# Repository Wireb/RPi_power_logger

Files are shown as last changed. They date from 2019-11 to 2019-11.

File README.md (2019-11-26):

# RPi Power Logger
These files are for my Raspberry Pi Zero based power data logger hat. 
 
License is MIT so do what you want with it just don't litigate me. 

Have had quite a few times where I needed actual run times of various battery powered devices. Built this device to collect both the battery voltage, current, and average power as well as up to 8 other voltage rails.

The simple use case is to put channel 0 in line with your battery powered device. This channel is based on the TI INA233 Bidirectional current and power sensor. It supports up to 36Vin and a wide range of currents depending on your choice for R17 and scaling factor. See the INA233 datasheet for more info. In my case of small battery powered devices I have optimized for a max current of 2A. Note the INA233 is set up for high side sensing and the RPi must be powered externally with a common ground with the circuit under test. Once inserted in the power lines just log into the Pi and start the perl script. It will generate a ./Power_data.csv file with all the readings taken every second until you kill the process. 

More advanced setups can use channels 1 - 8 to monitor internal voltage rails. I use this to see which rail is failing first and if any become unstable when the battery voltage is low. Channels 1 - 3 support up to 4V max, channles 4 - 6 support up to 6V max, and channels 7 and 8 support up to 15V max. Note all channels are on a common ground reference.

There is configuration variables in the Perl script for which channels to sample, time between samples, max sample time, and some INA233 configuration. (see Raspbian-Perl directory for more info)

## KiCad
This is a KiCad 5.1.4 project. Both the original KiCad logics, PCB files and a xlsx bill of material can be found here as well as a PDF file of the logics and a top side image of the PCB.   

## Raspbian-Perl
This is the perl script I use to collect the data on the Raspberry Pi. Sample output .csv file of just channel 0 and a processed graph in xlsx format are also included. 

Copyright (c) 2019 Peter Shabino

Permission is hereby granted, free of charge, to any person obtaining a copy of this hardware, software, and associated documentation files 
(the "Product"), to deal in the Product without restriction, including without limitation the rights to use, copy, modify, merge, publish, 
distribute, sublicense, and/or sell copies of the Product, and to permit persons to whom the Product is furnished to do so, subject to the 
following conditions:

The above copyright notice and this permission notice shall be included in all copies or substantial portions of the Product.

THE PRODUCT IS PROVIDED "AS IS", WITHOUT WARRANTY OF ANY KIND, EXPRESS OR IMPLIED, INCLUDING BUT NOT LIMITED TO THE WARRANTIES OF 
MERCHANTABILITY, FITNESS FOR A PARTICULAR PURPOSE AND NONINFRINGEMENT. IN NO EVENT SHALL THE AUTHORS OR COPYRIGHT HOLDERS BE LIABLE 
FOR ANY CLAIM, DAMAGES OR OTHER LIABILITY, WHETHER IN AN ACTION OF CONTRACT, TORT OR OTHERWISE, ARISING FROM, OUT OF OR IN CONNECTION 
WITH THE PRODUCT OR THE USE OR OTHER DEALINGS IN THE PRODUCT.

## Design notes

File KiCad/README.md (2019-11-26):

# KiCad project files
These are KiCad 5.1.4 compatible files. Not going any deeper than that :)

If you just want PCBs now they are available on OSHpark here: 
https://oshpark.com/shared_projects/NPSVbO1J


## partnumber.csv
CSV file of all unique part numbers. (used for ordering)

## refdes.csv
CSV file of every part by refdes. (used for building)

## RPi_power_logger.xlsx
Bill of Materials in Microsoft Excel format. Includes links to Digikey. 

## RPi_power_logger.pdf
PDF file of logics for easy viewing without KiCad installed. 

## RPi_power_logger_PCB.png
Image file of the top side of the PCB and refdes for easy viewing without KiCad installed. 

Copyright (c) 2019 Peter Shabino

Permission is hereby granted, free of charge, to any person obtaining a copy of this hardware, software, and associated documentation files 
(the "Product"), to deal in the Product without restriction, including without limitation the rights to use, copy, modify, merge, publish, 
distribute, sublicense, and/or sell copies of the Product, and to permit persons to whom the Product is furnished to do so, subject to the 
following conditions:

The above copyright notice and this permission notice shall be included in all copies or substantial portions of the Product.

THE PRODUCT IS PROVIDED "AS IS", WITHOUT WARRANTY OF ANY KIND, EXPRESS OR IMPLIED, INCLUDING BUT NOT LIMITED TO THE WARRANTIES OF 
MERCHANTABILITY, FITNESS FOR A PARTICULAR PURPOSE AND NONINFRINGEMENT. IN NO EVENT SHALL THE AUTHORS OR COPYRIGHT HOLDERS BE LIABLE 
FOR ANY CLAIM, DAMAGES OR OTHER LIABILITY, WHETHER IN AN ACTION OF CONTRACT, TORT OR OTHERWISE, ARISING FROM, OUT OF OR IN CONNECTION 
WITH THE PRODUCT OR THE USE OR OTHER DEALINGS IN THE PRODUCT.

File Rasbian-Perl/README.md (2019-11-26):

# RPi_datalogger.pl
This is the main Perl script for data logging. 
Edit the file in any text editor to configure the following:

```perl
############################
# configuration value start
############################
my $output_file = "./Power_data.csv";	# output file path and name for readings
my $stop_file = "./stop";				# file to create to stop the loop
my $channels = "12345678"; 				# optional voltage channels enables. Valid values are 1 to 8. If that number is in this string (any order) the data will be collected along with the power data. 
my $sample_every = 1;					# sample every x seconds. A value of 0 will sample as fast as possible but the time data will still be in seconds (future upgrade sub second time base) 
my $stop_time = 0;						# in s 0 = run forever
############################
# configuration value end
############################

# constants (See INA233 datasheet for more info!!)
my $max_current = 2;	# in Amps
my $R_shunt = 0.075;  	# in Ohms
```

## Power_data.csv
This is a sample raw CSV file as produced by the above Perl script.

Note only channle 0 was enabled in this sample. If channels 1 - 8 were enabled there would be one more voltage column per enabled channel. 

## Sample_graph.xlsx
Example Microsoft Excel spreadsheet with a graph of the sample data. 

Copyright (c) 2019 Peter Shabino

Permission is hereby granted, free of charge, to any person obtaining a copy of this hardware, software, and associated documentation files 
(the "Product"), to deal in the Product without restriction, including without limitation the rights to use, copy, modify, merge, publish, 
distribute, sublicense, and/or sell copies of the Product, and to permit persons to whom the Product is furnished to do so, subject to the 
following conditions:

The above copyright notice and this permission notice shall be included in all copies or substantial portions of the Product.

THE PRODUCT IS PROVIDED "AS IS", WITHOUT WARRANTY OF ANY KIND, EXPRESS OR IMPLIED, INCLUDING BUT NOT LIMITED TO THE WARRANTIES OF 
MERCHANTABILITY, FITNESS FOR A PARTICULAR PURPOSE AND NONINFRINGEMENT. IN NO EVENT SHALL THE AUTHORS OR COPYRIGHT HOLDERS BE LIABLE 
FOR ANY CLAIM, DAMAGES OR OTHER LIABILITY, WHETHER IN AN ACTION OF CONTRACT, TORT OR OTHERWISE, ARISING FROM, OUT OF OR IN CONNECTION 
WITH THE PRODUCT OR THE USE OR OTHER DEALINGS IN THE PRODUCT.

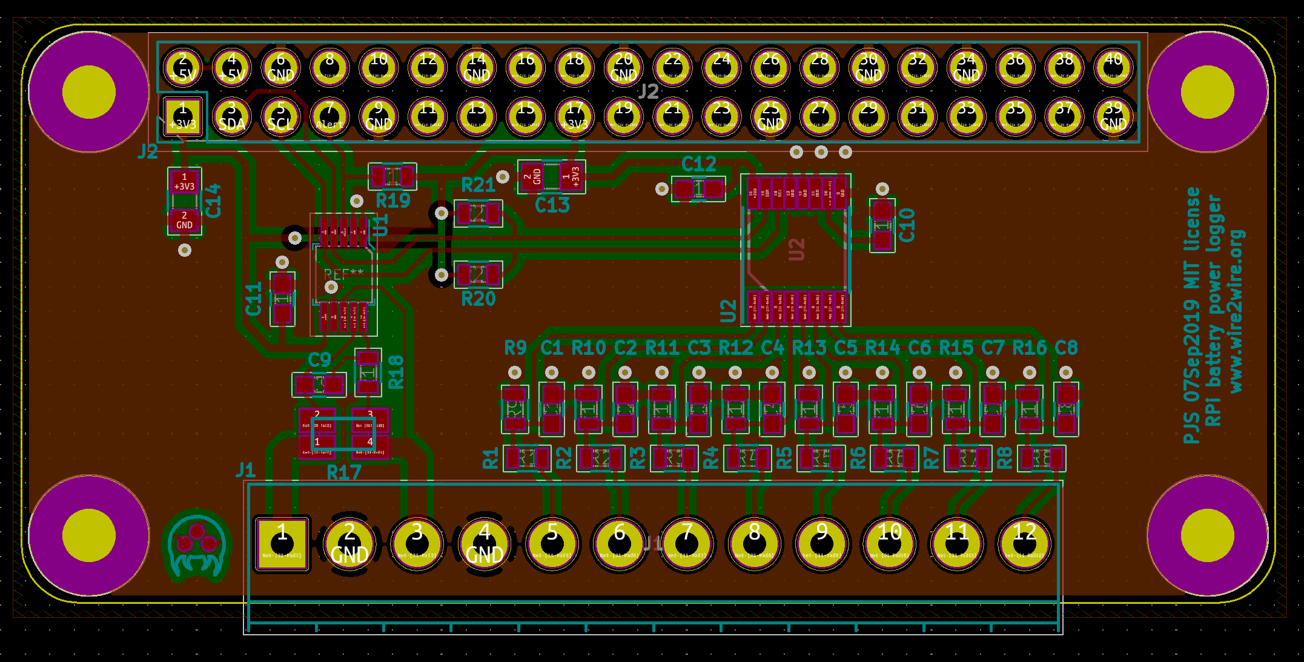
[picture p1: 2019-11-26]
KiCad/RPi_power_logger_PCB.png

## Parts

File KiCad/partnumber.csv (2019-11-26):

Q | part number | footprint | ref_des
12 | 0.1uF | Capacitors_SMD:C_0603 | C11 C9 C12 C10 C1 C2 C3 C4 C5 C6 C7 C8
8 | 100k | Resistors_SMD:R_0603 | R9 R10 R11 R12 R13 R14 R15 R16
3 | 10k | Resistors_SMD:R_0603 | R19 R20 R21
2 | 10uF | Capacitors_SMD:C_0805 | C13 C14
3 | 140k | Resistors_SMD:R_0603 | R4 R5 R6
2 | 500k | Resistors_SMD:R_0603 | R7 R8
1 | 5 | Resistors_SMD:R_0603 | R18
3 | 60k | Resistors_SMD:R_0603 | R1 R2 R3
1 | INA233 | digikey-footprints:MSOP-10_W3mm | U1
1 | LVK12R075DER | PJS_smt_parts:LVK12 | R17
1 | Metroid | PJS-icons:metroid | icon1
1 | NCD9830 | Housings_SSOP:TSSOP-16_4.4x5mm_Pitch0.65mm | U2
1 | OSTTE120104 | TerminalBlocks_Phoenix:TerminalBlock_Phoenix_PT-3.5mm_12pol | J1
1 | Raspberry_Pi_2_3 | Pin_Headers:Pin_Header_Straight_2x20_Pitch2.54mm | J2

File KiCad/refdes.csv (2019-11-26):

ref_des | part number | footprint
C1 | 0.1uF | Capacitors_SMD:C_0603
C10 | 0.1uF | Capacitors_SMD:C_0603
C11 | 0.1uF | Capacitors_SMD:C_0603
C12 | 0.1uF | Capacitors_SMD:C_0603
C13 | 10uF | Capacitors_SMD:C_0805
C14 | 10uF | Capacitors_SMD:C_0805
C2 | 0.1uF | Capacitors_SMD:C_0603
C3 | 0.1uF | Capacitors_SMD:C_0603
C4 | 0.1uF | Capacitors_SMD:C_0603
C5 | 0.1uF | Capacitors_SMD:C_0603
C6 | 0.1uF | Capacitors_SMD:C_0603
C7 | 0.1uF | Capacitors_SMD:C_0603
C8 | 0.1uF | Capacitors_SMD:C_0603
C9 | 0.1uF | Capacitors_SMD:C_0603
J1 | OSTTE120104 | TerminalBlocks_Phoenix:TerminalBlock_Phoenix_PT-3.5mm_12pol
J2 | Raspberry_Pi_2_3 | Pin_Headers:Pin_Header_Straight_2x20_Pitch2.54mm
R1 | 60k | Resistors_SMD:R_0603
R10 | 100k | Resistors_SMD:R_0603
R11 | 100k | Resistors_SMD:R_0603
R12 | 100k | Resistors_SMD:R_0603
R13 | 100k | Resistors_SMD:R_0603
R14 | 100k | Resistors_SMD:R_0603
R15 | 100k | Resistors_SMD:R_0603
R16 | 100k | Resistors_SMD:R_0603
R17 | LVK12R075DER | PJS_smt_parts:LVK12
R18 | 5 | Resistors_SMD:R_0603
R19 | 10k | Resistors_SMD:R_0603
R2 | 60k | Resistors_SMD:R_0603
R20 | 10k | Resistors_SMD:R_0603
R21 | 10k | Resistors_SMD:R_0603
R3 | 60k | Resistors_SMD:R_0603
R4 | 140k | Resistors_SMD:R_0603
R5 | 140k | Resistors_SMD:R_0603
R6 | 140k | Resistors_SMD:R_0603
R7 | 500k | Resistors_SMD:R_0603
R8 | 500k | Resistors_SMD:R_0603
R9 | 100k | Resistors_SMD:R_0603
U1 | INA233 | digikey-footprints:MSOP-10_W3mm
U2 | NCD9830 | Housings_SSOP:TSSOP-16_4.4x5mm_Pitch0.65mm
icon1 | Metroid | PJS-icons:metroid

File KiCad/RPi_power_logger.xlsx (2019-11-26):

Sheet: partnumber
Q | part number | footprint | ref_des | vendor | vendor PN | digikey PN | link
12 | 0.1uF | Capacitors_SMD:C_0603 | C11 C9 C12 C10 C1 C2 C3 C4 C5 C6 C7 C8 | samsung | CL10B104KB8NNNC | 1276-1000-1-ND | https://www.digikey.com/product-detail/en/samsung-electro-mechanics/CL10B104KB8NNNC/1276-1000-1-ND/3889086
8 | 100k | Resistors_SMD:R_0603 | R9 R10 R11 R12 R13 R14 R15 R16 | Stackpole | RMCF0603FT100K | RMCF0603FT100KCT-ND | https://www.digikey.com/product-detail/en/stackpole-electronics-inc/RMCF0603FT100K/RMCF0603FT100KCT-ND/1943118
3 | 10k | Resistors_SMD:R_0603 | R19 R20 R21 | Stackpole | RNCP0603FTD10K0 | RNCP0603FTD10K0CT-ND | https://www.digikey.com/product-detail/en/stackpole-electronics-inc/RNCP0603FTD10K0/RNCP0603FTD10K0CT-ND/2240478
2 | 10uF | Capacitors_SMD:C_0805 | C13 C14 | samsung | CL21A106KQFNNNG | 1276-6457-1-ND | https://www.digikey.com/product-detail/en/samsung-electro-mechanics/CL21A106KQFNNNG/1276-6457-1-ND/5958085
3 | 140k | Resistors_SMD:R_0603 | R4 R5 R6 | Stackpole | RMCF0603FT140K | RMCF0603FT140KCT-ND | https://www.digikey.com/product-detail/en/stackpole-electronics-inc/RMCF0603FT140K/RMCF0603FT140KCT-ND/4250692
2 | 500k | Resistors_SMD:R_0603 | R7 R8 | Stackpole | RMCF0603FT499K | RMCF0603FT499KCT-ND | https://www.digikey.com/product-detail/en/stackpole-electronics-inc/RMCF0603FT499K/RMCF0603FT499KCT-ND/1943138
1 | 5 | Resistors_SMD:R_0603 | R18 | KOA Sper | RK73H1JTTD4R99F | 2019-RK73H1JTTD4R99FCT-ND | https://www.digikey.com/product-detail/en/koa-speer-electronics-inc/RK73H1JTTD4R99F/2019-RK73H1JTTD4R99FCT-ND/9847147
3 | 60k | Resistors_SMD:R_0603 | R1 R2 R3 | Stackpole | RMCF0603FT60K4 | RMCF0603FT60K4CT-ND | https://www.digikey.com/product-detail/en/stackpole-electronics-inc/RMCF0603FT60K4/RMCF0603FT60K4CT-ND/1943106
1 | INA233 | digikey-footprints:MSOP-10_W3mm | U1 | TI | INA233AIDGSR | 296-48136-1-ND | https://www.digikey.com/product-detail/en/texas-instruments/INA233AIDGSR/296-48136-1-ND/8347451
1 | LVK12R075DER | PJS_smt_parts:LVK12 | R17 | Ohmite | LVK12R010DER | LVK12R010DERCT-ND | https://www.digikey.com/product-detail/en/ohmite/LVK12R075DER/LVK12R075DERCT-ND/5125261
0 | Metroid | PJS-icons:metroid | icon1
1 | NCD9830 | Housings_SSOP:TSSOP-16_4.4x5mm_Pitch0.65mm | U2 | ON Semi | NCD9830DBR2G | NCD9830DBR2GOSCT-ND | https://www.digikey.com/product-detail/en/on-semiconductor/NCD9830DBR2G/NCD9830DBR2GOSCT-ND/9086945
1 | OSTTE120104 | TerminalBlocks_Phoenix:TerminalBlock_Phoenix_PT-3.5mm_12pol | J1 | On Shore | OSTTE120104 | ED2737-ND | https://www.digikey.com/product-detail/en/OSTTE120104/ED2737-ND/2351813/?itemSeq=303015730
1 | Raspberry_Pi_2_3 | Pin_Headers:Pin_Header_Straight_2x20_Pitch2.54mm | J2 | Sullins Conn | PPTC102LFBN-RC | S7078-ND | https://www.digikey.com/product-detail/en/sullins-connector-solutions/PPTC102LFBN-RC/S7078-ND/810216

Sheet: Calcs
Max currnet | 2 | A
Current LSB | 6.103515625e-05
 |  |  |  | R1 | R2 | Vmax | I insert (mA)
Rshunt | 0.01 | Ohms | ch 1 - 3 | 60000 | 100000 | 4 | 0.025
CAL | 8388.608 |  | ch 4 - 6 | 140000 | 100000 | 6 | 0.025
 | 8388 | round | ch 7 - 8 | 500000 | 100000 | 15 | 0.025
CAL | 20C4 | hex
 | V
m | 8
Y (value in) | 1
R | 2
b | 0
X | 0.00125

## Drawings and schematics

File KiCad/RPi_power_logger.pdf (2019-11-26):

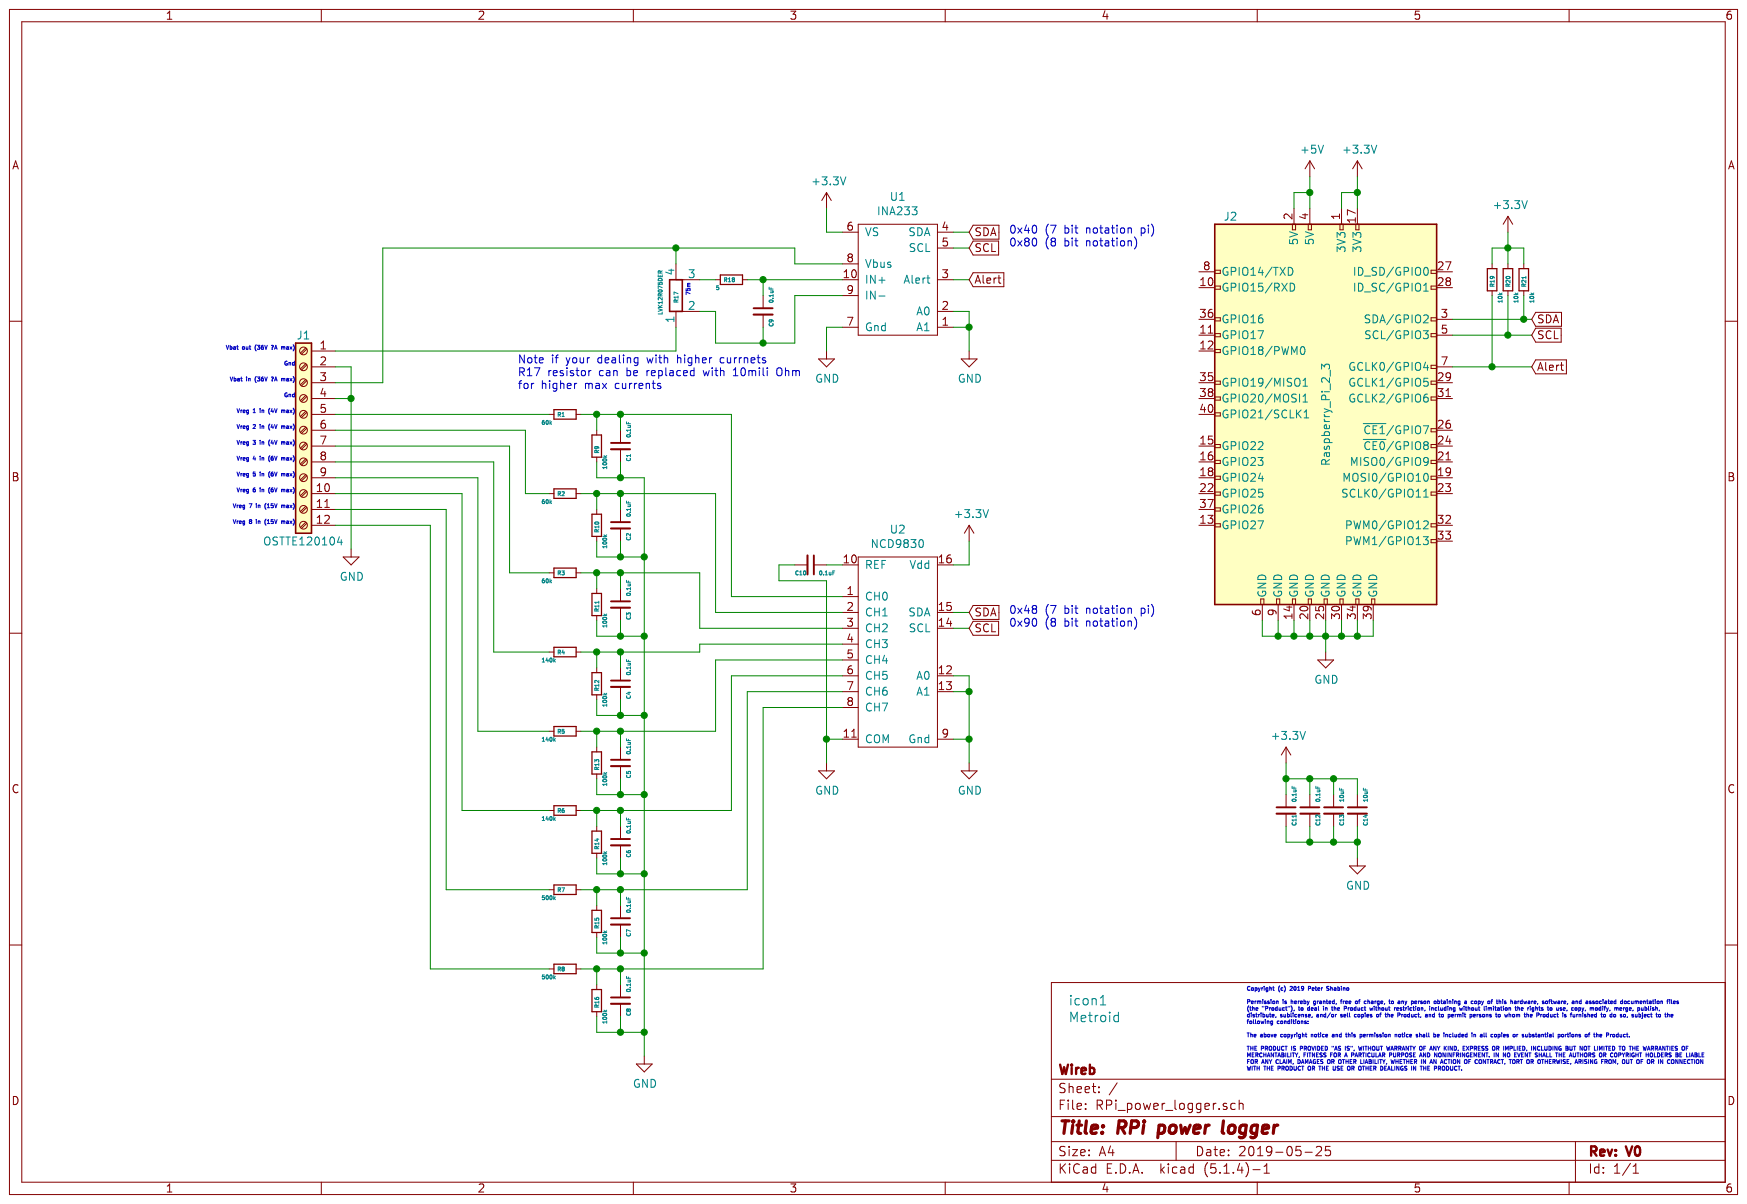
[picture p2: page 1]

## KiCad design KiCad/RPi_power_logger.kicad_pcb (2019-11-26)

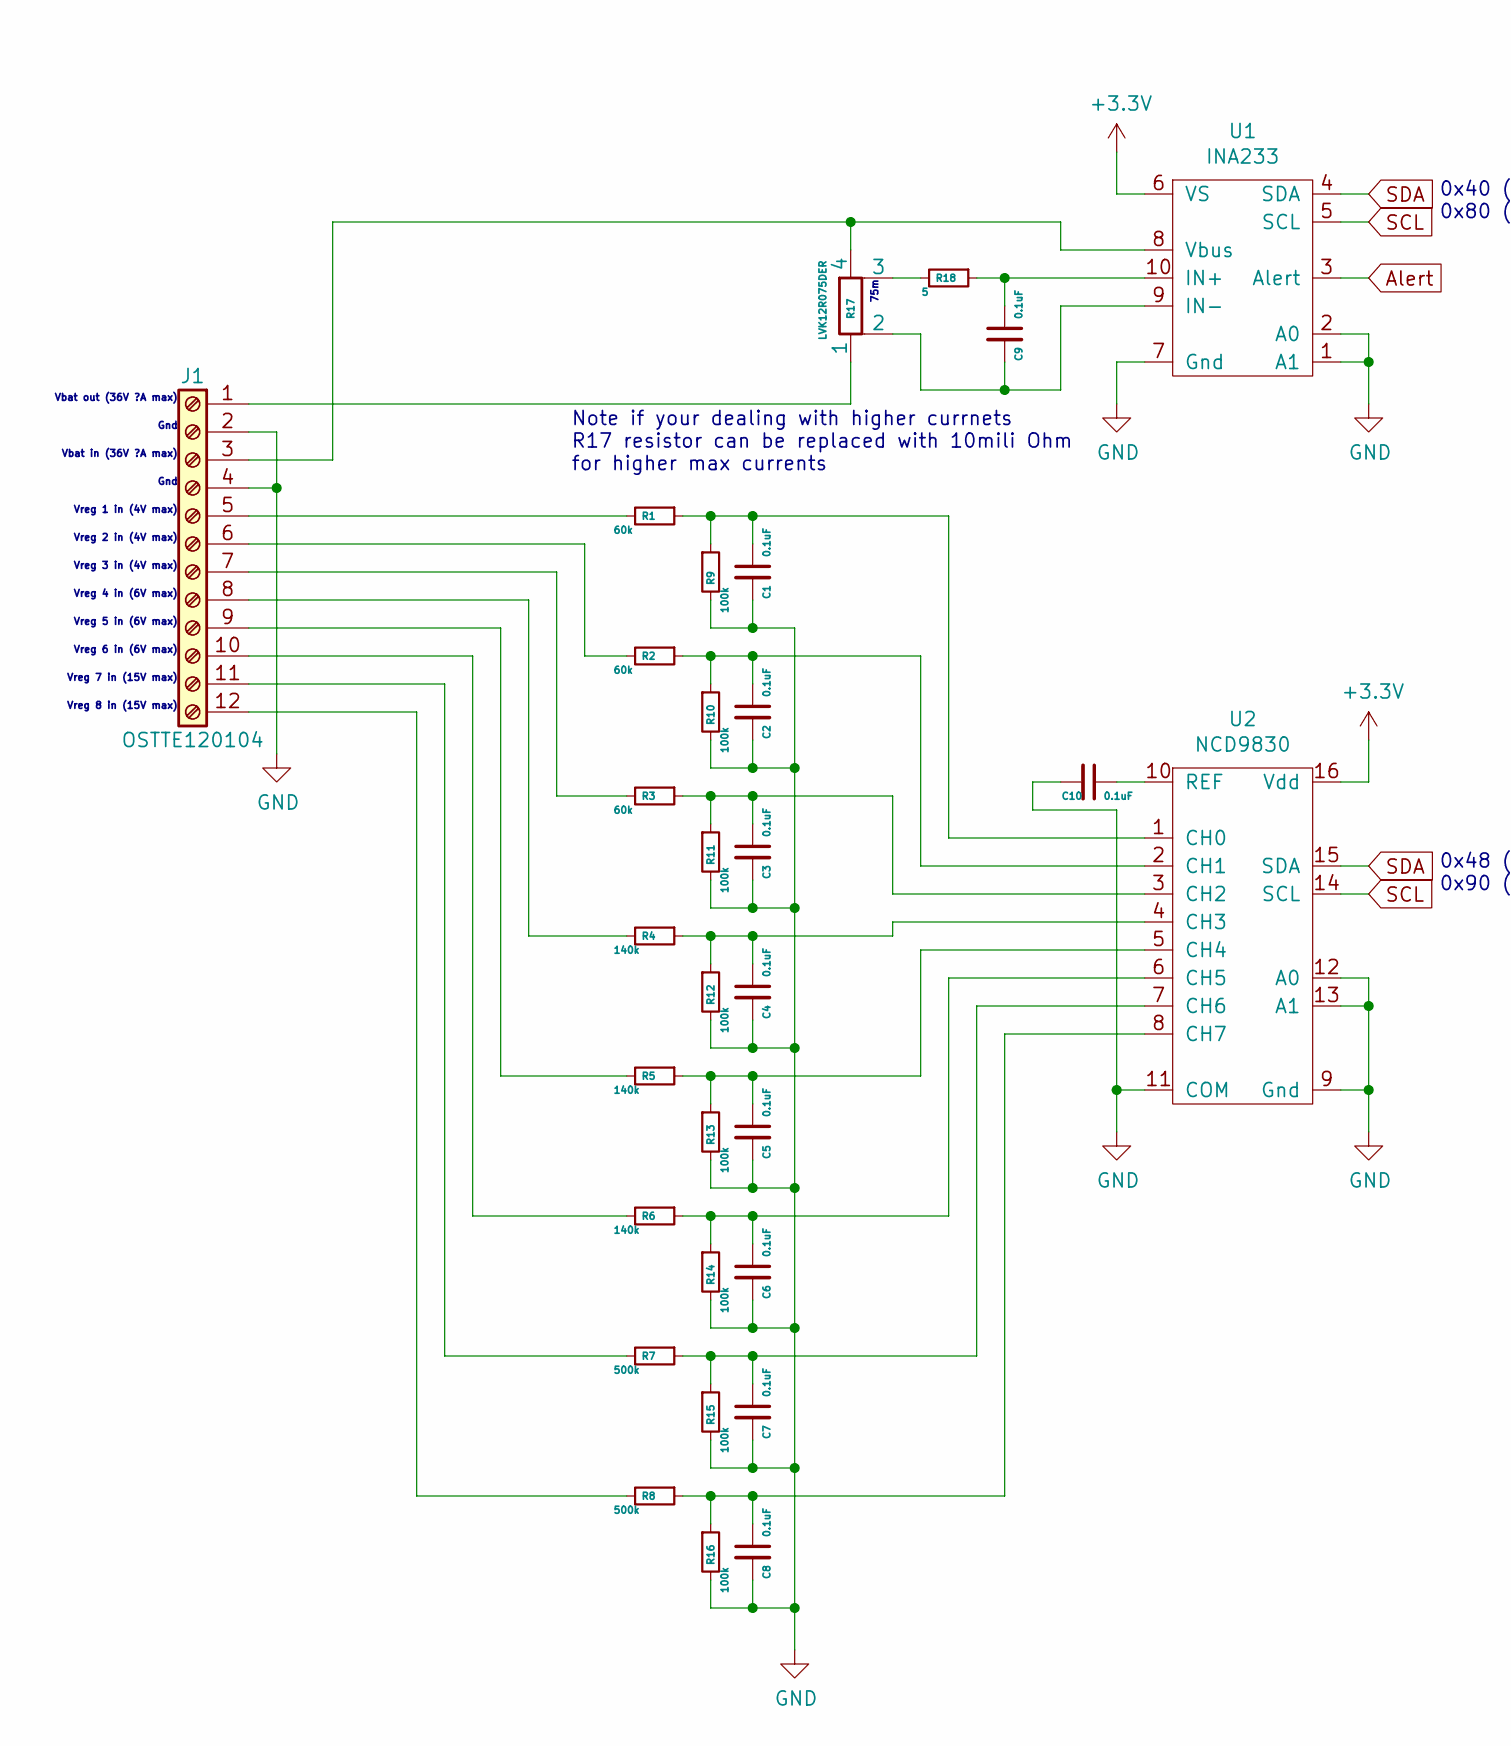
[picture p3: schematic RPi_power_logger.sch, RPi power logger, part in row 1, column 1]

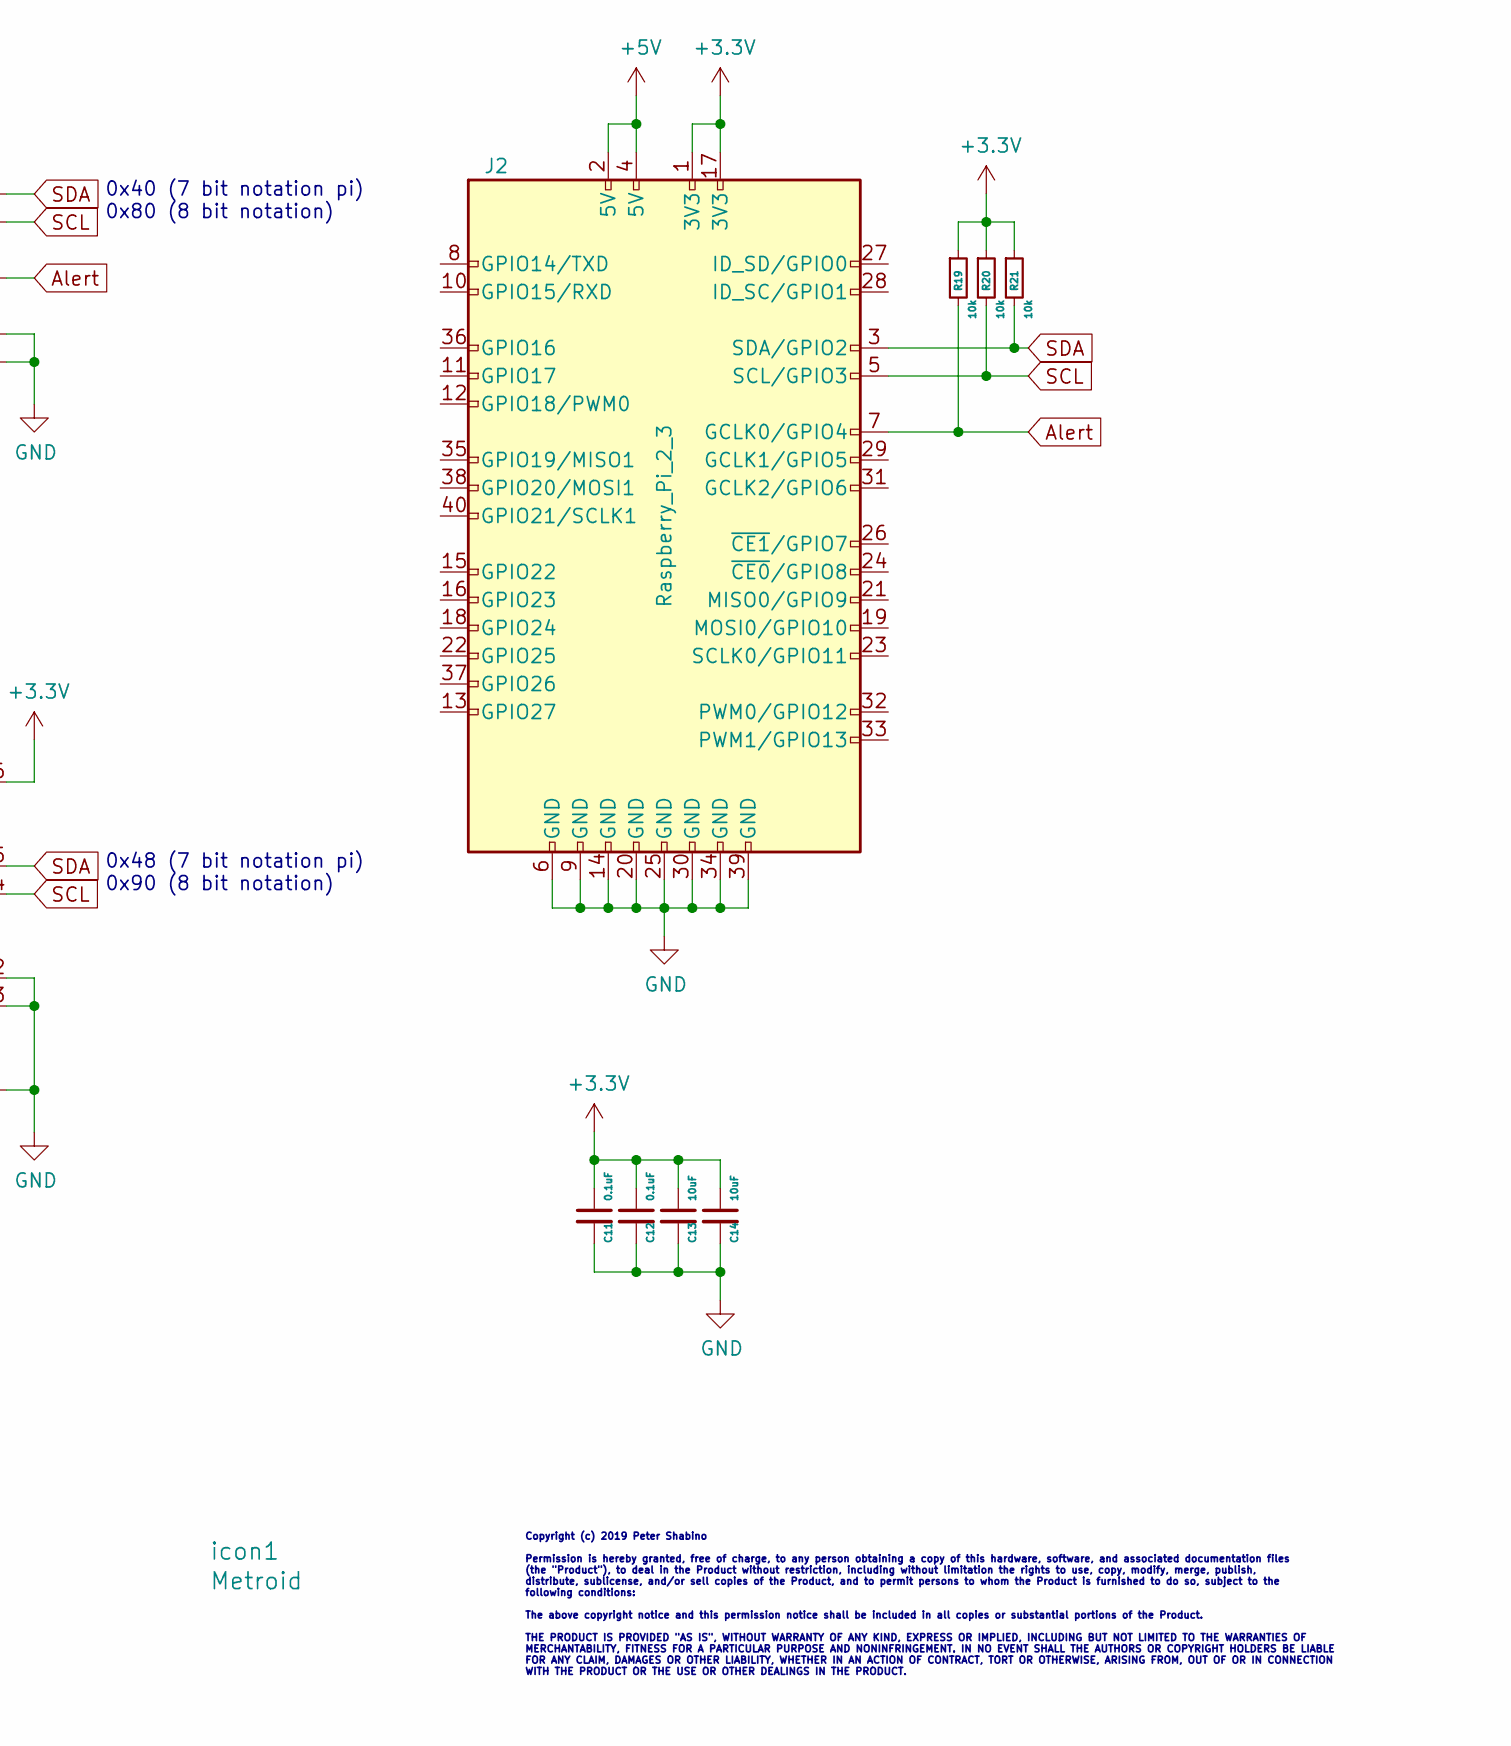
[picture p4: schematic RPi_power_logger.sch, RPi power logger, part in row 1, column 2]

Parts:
C1, C2, C3, C4, C5, C6, C7, C8, C9, C10, C11, C12: 0.1uF; C_0603
C13, C14: 10uF; C_0805
J1: OSTTE120104; TerminalBlock_Phoenix_PT-3.5mm_12pol
J2: Raspberry_Pi_2_3; Pin_Header_Straight_2x20_Pitch2.54mm
R1, R2, R3: 60k; R_0603
R4, R5, R6: 140k; R_0603
R7, R8: 500k; R_0603
R9, R10, R11, R12, R13, R14, R15, R16: 100k; R_0603
R17: LVK12R075DER; LVK12
R18: 5; R_0603
R19, R20, R21: 10k; R_0603
U1: INA233; MSOP-10_W3mm
U2: NCD9830; TSSOP-16_4.4x5mm_Pitch0.65mm
icon1: Metroid; metroid

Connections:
+3V3: C11.1, C12.1, C13.1, C14.1, J2.1 (3V3), J2.17 (3V3), R19.1, R20.1, R21.1, U1.6 (VS), U2.16 (Vdd)
+5V: J2.2 (5V), J2.4 (5V)
Alert: J2.7 (GCLK0/GPIO4), R19.2, U1.3 (Alert)
GND: C1.2, C2.2, C3.2, C4.2, C5.2, C6.2, C7.2, C8.2, C10.2, C11.2, C12.2, C13.2, C14.2, J1.2, J1.4, J2.6 (GND), J2.9 (GND), J2.14 (GND), J2.20 (GND), J2.25 (GND), J2.30 (GND), J2.34 (GND), J2.39 (GND), R9.2, R10.2, R11.2, R12.2, R13.2, R14.2, R15.2, R16.2, U1.1 (A1), U1.2 (A0), U1.7 (Gnd), U2.9 (Gnd), U2.11 (COM), U2.12 (A0), U2.13 (A1)
unnamed: C1.1, R1.1, R9.1, U2.1 (CH0)
unnamed: C2.1, R2.1, R10.1, U2.2 (CH1)
unnamed: C3.1, R3.1, R11.1, U2.3 (CH2)
unnamed: C4.1, R4.1, R12.1, U2.4 (CH3)
unnamed: C5.1, R5.1, R13.1, U2.5 (CH4)
unnamed: C6.1, R6.1, R14.1, U2.6 (CH5)
unnamed: C7.1, R7.1, R15.1, U2.7 (CH6)
unnamed: C8.1, R8.1, R16.1, U2.8 (CH7)
unnamed: C9.1, R18.1, U1.10 (IN+)
unnamed: C9.2, R17.2, U1.9 (IN-)
unnamed: C10.1, U2.10 (REF)
unnamed: J1.1, R17.1
unnamed: J1.3, R17.4, U1.8 (Vbus)
unnamed: J1.5, R1.2
unnamed: J1.6, R2.2
unnamed: J1.7, R3.2
unnamed: J1.8, R4.2
unnamed: J1.9, R5.2
unnamed: J1.10, R6.2
unnamed: J1.11, R7.2
unnamed: J1.12, R8.2
unnamed: R17.3, R18.2
SCL: J2.5 (SCL/GPIO3), R20.2, U1.5 (SCL), U2.14 (SCL)
SDA: J2.3 (SDA/GPIO2), R21.2, U1.4 (SDA), U2.15 (SDA)

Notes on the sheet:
0x40 (7 bit notation pi) 0x80 (8 bit notation)
0x48 (7 bit notation pi) 0x90 (8 bit notation)
Vbat in (36V ?A max)
Gnd
Vbat out (36V ?A max)
Vreg 1 in (4V max)
Vreg 2 in (4V max)
Vreg 3 in (4V max)
Vreg 4 in (6V max)
Vreg 5 in (6V max)
Vreg 6 in (6V max)
Vreg 7 in (15V max)
Vreg 8 in (15V max)
Copyright (c) 2019 Peter Shabino Permission is hereby granted, free of charge, to any person obtaining a copy of this hardware, software, and associated documentation files (the "Product"), to deal in the Product without restriction, including without limitation the rights to use, copy, modify, mer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
75m
Note if your dealing with higher currnets R17 resistor can be replaced with 10mili Ohm for higher max currents

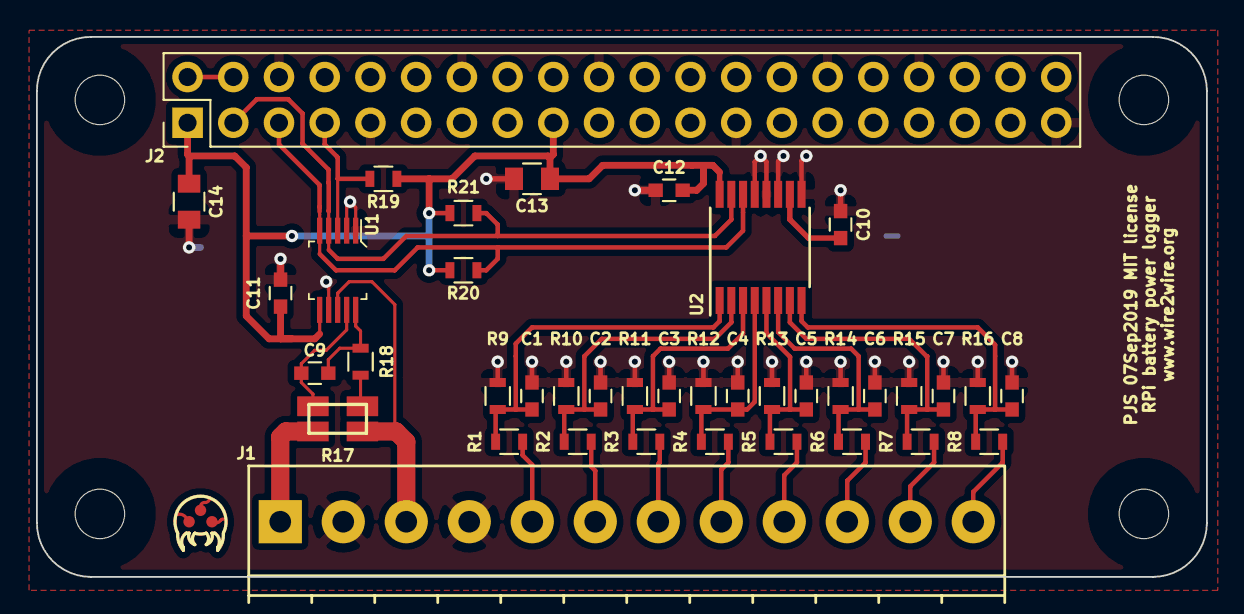
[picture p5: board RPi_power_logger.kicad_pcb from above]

Board: 2 copper layers, 65.0 x 30.0 mm, 40 parts (0 on the bottom side), 28 nets.

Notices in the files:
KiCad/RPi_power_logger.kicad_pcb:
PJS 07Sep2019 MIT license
